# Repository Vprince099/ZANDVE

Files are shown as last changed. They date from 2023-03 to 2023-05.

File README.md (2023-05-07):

# UPDATE 04/04/2023
## Revision Log
* 5/6 Added upgraded Stepper Mounts, Bug fixes on Rear Gantry Panel Base Parts
* 4/4 Type-V stls and cad loaded
* 4/2 Added Built in supports for 6 parts, CAD Complete for Type-V
* 4/1 Parts fixes and cad update 
* 3/31 Added Top Hat XL for users looking to run umbilicals on a canbus
* 3/29 [BOM](https://docs.google.com/spreadsheets/d/1_rfxcacC1YKR7S-sEJu0cIL2j3crcf0YIQrBYNYs7lM/edit?usp=sharing) is complete, I will continue to add links for vendors as time permits. 

## Please see below for the project status.
Work ID | Description | Status | LOE | Target Date |
| :--- | :--- | :--- | :---: | :---: |
1 | Finish upload of Type-Z | Done | Medium | 3/27/23
2.1 | Finish Bom | Done | Medium | 3/29/23
2.2 | Work on a basic Assembly guide | Not Started | High | On-Going
3 | Start Type-V Cad | Done | Low | 4/02/23
3.1 | Build Type-V | Waiting on Parts | Low | 4/30/23
3.2 | Upload Everything for Type-V | Done | Medium | 4/4/22
4 | Implement Hydra for Type-Z | Done | Low | 5/1/23
4.1 | Testing of Hydra | Done | Low | 5/1/23
4.2 | Release V1 of Type Z | Updating CAD | Medium | 5/13/23
5 | Implement Trident for Type-V | Dependant on Type-V Release | High | TBD
5.1 | Testing of Trident | Parts Not Ordered | High | TBD
5.2 | Release V1 of Type-V | Dependant on Testing | Medium | TBD

## Purpose
This is a placeholder for uploading the projects I am working on

<a href="https://www.buymeacoffee.com/VengefulDesign" target="_blank">Buy Me A Coffee</a>

Project ZANDVE is licensed under the
GNU General Public License v3.0<br><br>

Credits to [ZeroGDesign/Mercury](https://github.com/ZeroGDesign/Mercury/)

Credits to [VoronDesign](https://github.com/VoronDesign/)

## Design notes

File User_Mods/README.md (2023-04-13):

# Mods

Printer mods for ZANDVE 3D printers
Remember to update this README when uploading new mod!

[How To Contribute](https://github.com/Vprince099/ZANDVE/blob/61768b7b6e2966e44ad4c9d49aaf2dfaacc2f230/User_Mods/how_to_contribute.md)

***Credit: This idea originates from [ZeroG](https://github.com/Vprince099/UserMods/tree/main/Mercury_One)***

## Directory structure

Create a folder containing your name (without spaces) and create a folder for your mod(s).

Suggested directory layout for your mod:
- `creator_name/`
  - `mod_name/`
    - `README.md` with a description, optionally build instructions and required parts
    - `stl/` folder with stereolithographical models, oriented correctly for printing
    - `cad/` folder with original design files (STEP, F3D, Scad, etc.) (optional)
    - `doc/` folder with supported documentation (optional)
    - `images/` folder with screen shots/renders/etc.

## Table structure

Update the following table with the information about your mod:
- Your name
- A link to your sub-folder
- A short description of your mod
- The build difficulty:
  - `:green_heart:` for :green_heart: (Easy)
  - `:blue_heart:` for :blue_heart: (Intermediate)
  - `:heart:` for :heart: (Advanced)

like so:
`
| Creator | [Mod title](link) | Description | Difficulty `

---

| Creator | Mod title | Description | Difficulty
| --- | --- | --- | --- |
| *JellyBob* | [*ZANDVE_Less-Frame*](./JellyBob/ZANDVE_Less-Frame) | A modification to remove the original front cross extrusion which makes it awkward to see the nozzle on build plate for first layer (poor-man’s 3DO nozzle cam) :)  |:green_heart:
| *LTSpenny* | [*ZANDVE_Left_Stepper Pillow_Bearing*](./LTSPENNY/ZANDVE/L_Stepper_Pillow_Bearing) | A modification to add a pillow bearing reusing readily available parts you should already have plenty of and implementation of Mercury 1.1 Bearing Stack.  |:green_heart:

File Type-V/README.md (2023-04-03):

# ZANDVE Enclosed E5+ Printer Code Name: Type V (**Files Loading Soon**)

This mod is is amalgamation of parts from the ZeroG (Mercury1) and Voron (Trident,V1.8,StealthBurner) for the Ender 5 Plus. The primary goal is to provide a enclosed Core-xy printer in similar fashion to Voron design language while still retaining the majority of the E5+ Frame and Z-Motion Systems.   

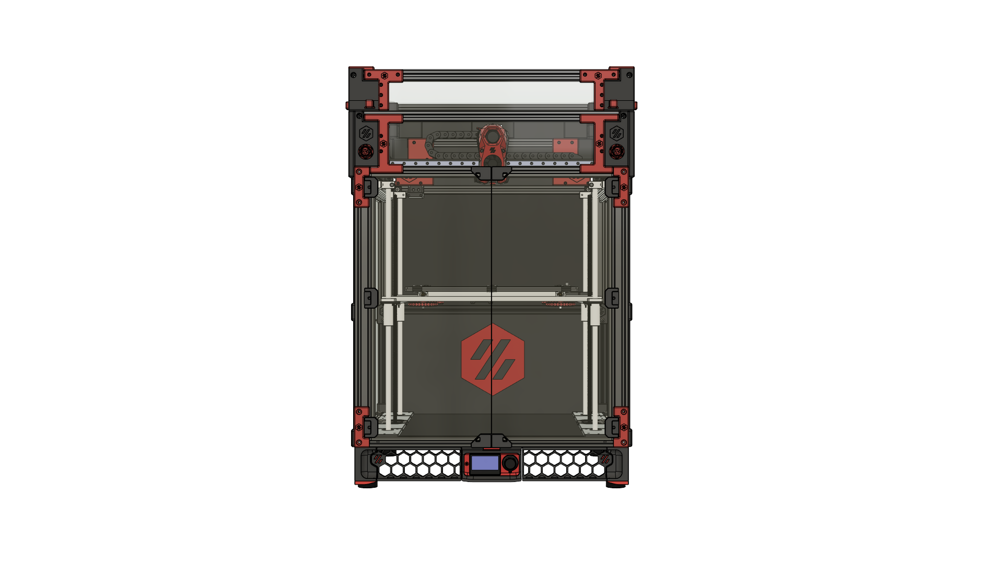
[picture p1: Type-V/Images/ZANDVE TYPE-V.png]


## Description

This version is targeted at anyone looking to retain the **VORON** badging. The **ZERO G** badged version can be found here [Type-Z](https://github.com/Vprince099/ZANDVE/tree/main/Type-Z). In order to provide a version that can be used by the entire E5 Plus community, I am starting with stock Z-Motion (a new upgrade will be released soon to allow for the tri-stepper upgrade Trident by Voron). 

This Version is intended to reduce the cost of conversion while still providing a Fully Enclosed CORE-XY Printer: 

* Estimated Conversion Cost from Stock **TBD**
* Estimated Conversion Cost from Mercury 1/1.1 **TBD**

## Dependencies

* **Please print in ABS or ASA**
* Due to the tight clearances of a part like this, I recommend this part be printed on a properly calibrated printer
* I **Do not** recommend scaling the parts via a slicer as you may have issues with fitment

## Bill of Materials

[BOM](https://docs.google.com/spreadsheets/d/1_rfxcacC1YKR7S-sEJu0cIL2j3crcf0YIQrBYNYs7lM/edit?usp=sharing), vendors and other sources will be added as time permits.

## Help

* Please reach out to me directly on discord if you have any issues or suggestions for this Mod 

## Authors

Vprince099 aka Vengeful Discord - Vengeful#8648

## Version History
    
* 0.1
    * Initial Release

## License

This project is licensed under the GNU GENERAL PUBLIC LICENSE - see the LICENSE.md file for details

## Acknowledgments

* ZeroG - Original Towers used to expand upon [Link to Project](https://github.com/ZeroGDesign/Mercury.git)
* Voron Design - V0 Team for Knob and Thread Appendage [Link to Project](https://github.com/VoronDesign/Voron-0.git)

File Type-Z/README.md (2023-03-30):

# ZANDVE Enclosed E5+ Code Name: Type Z

This mod is an amalgamation  of parts from the ZeroG (Mercury1) and Voron (Trident,V1.8,V0,StealthBurner) for the Ender 5 **PLUS**. The primary goal is to provide a enclosed Core-xy printer in similar fashion to Voron design language while still retaining the majority of the E5+ Frame and Z-Motion Systems.   

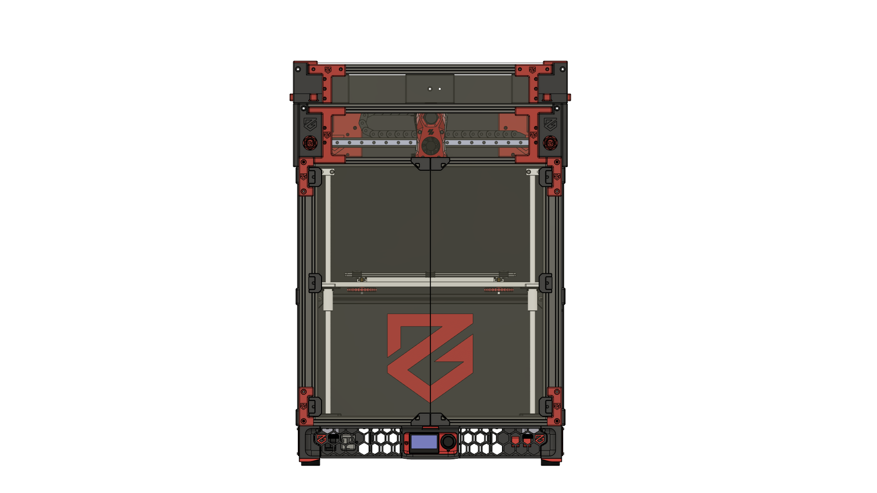
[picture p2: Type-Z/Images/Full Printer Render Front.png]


## Description

This version is targeted at anyone looking to retain the **ZERO G** badging. The **VORON** badged version can be found here [Type-V](https://github.com/Vprince099/ZANDVE/tree/main/Type-V). In order to provide a version that can be used by the entire E5 Plus community, I am starting with stock Z-Motion (a new upgrade will be released soon to allow for the tri-stepper upgrade HYDRA by ZERO G). 

This Version is intended to reduce the cost of conversion while still providing a Fully Enclosed CORE-XY Printer: 

* Estimated Conversion Cost from Stock **TBD**
* Estimated Conversion Cost from Mercury 1/1.1 **TBD**

## Dependencies

* **Please print in ABS or ASA**
* Due to the tight clearances of a part like this, I recommend this part be printed on a properly calibrated printer
* I **Do not** recommend scaling the parts via a slicer as you may have issues with fitment

## Bill of Materials

[BOM](https://docs.google.com/spreadsheets/d/1_rfxcacC1YKR7S-sEJu0cIL2j3crcf0YIQrBYNYs7lM/edit?usp=sharing), vendors and other sources will be added as time permits.

## Help

* Please reach out to me directly on discord if you have any issues or suggestions for this Mod 

## Authors

Vprince099 aka Vengeful Discord - Vengeful#8648

## Version History
    
* 0.1
    * Initial Release

## License

This project is licensed under the GNU GENERAL PUBLIC LICENSE - see the LICENSE.md file for details

## Acknowledgments

* Credits to [ZeroGDesign/Mercury](https://github.com/ZeroGDesign/Mercury/)
* Credits to [VoronDesign](https://github.com/VoronDesign/)

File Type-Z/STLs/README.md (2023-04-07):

* Can Bus adapter for Cable chains [link](https://www.printables.com/model/320325-btt-ebb36-canbus-voron-cw2-mount-moons-pancake-mot)
* Stealthburner Parts [link](https://github.com/VoronDesign/Voron-Stealthburner.git)

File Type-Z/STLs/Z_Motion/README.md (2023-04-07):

# Credits 
* Z Stepper Mounts from [VoronDesign](https://github.com/VoronDesign/)

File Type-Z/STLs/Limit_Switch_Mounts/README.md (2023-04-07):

# Credits 
* Beacon SB Xcarriage from [Annex](https://github.com/Annex-Engineering/Annex-Engineering_User_Mods/tree/main/Printers/Non_Annex_Printers/VORON_Printers/VORON_V2dot4/annex_dev-stealthburner_beacon_x_c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)
* Mech endstop retrofitted from Voron Trident [VoronDesign](https://github.com/VoronDesign/)
* X-endstop [ZeroGDesign/Mercury](https://github.com/ZeroGDesign/Mercury/) styling
* Badging added to match [ZeroGDesign/Mercury](https://github.com/ZeroGDesign/Mercury/) styling
* All other parts are unique to the ZANDVE

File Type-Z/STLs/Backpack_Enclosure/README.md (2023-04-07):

# Credits 
* Parts retrofitted from Voron 1.8 [VoronDesign](https://github.com/VoronDesign/)
* Adapted to mount on 2040 Extrusions

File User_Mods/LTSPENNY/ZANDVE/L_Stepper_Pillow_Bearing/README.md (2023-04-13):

**Purpose:** Using the standard NEMA17 stepper motor 17HE19-2004S from Mercury 1.1 BOM with ZANDVE Build, found that the Left Stepper Mount toothed gear was on the far edge of the stepper shaft. This can cause issues with the shaft receiving side loads and leading to bending the shaft, breaking or early failure of stepper. After discussing with jellybob and Vprince099, the solution to be implemented is a new stepper mount configuration being added to the ZANDVE BOM. New steppers will have longer shafts with a bearing on the bottom stepper mount. Interim, I modded the files to add a pillow block with items you should have readily available from the Ender 5/plus teardown. I've also modified the slots for the bearing stacks to accomodate the extra shims in the new Merc. 1.1 release that aliviates possible belt wear issues experienced with previous versions.

Printing Instructions:
* All ZANDVE STL Slicer settings Apply. ASA/ABS
* Print with supports on build plate. 
* Locate old V-Slot wheel, use a 5mm shaft or similar to push or pull one of the bearings out.
* Press fit bearing on the side the Toothed Gear will go into.
* Assemble steppers onto top stepper mount, install toothed gear. 
* Assemble rest as normal.

* **Version Changes**
* **V.0** - Original Pillow Block addition to Left Stepper Mount
* **V.1** - Added space to allow full Mercury 1.1 Bearing Stack install. (**CURRENT UPLOADED VERSION**)

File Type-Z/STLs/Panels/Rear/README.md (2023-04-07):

# Credits 
* Parts retrofitted from Voron Trident [VoronDesign](https://github.com/VoronDesign/)
* Same clips as Trident 4mm
* Added 2020 Etrusion endcaps due to 2040 Rear Frame

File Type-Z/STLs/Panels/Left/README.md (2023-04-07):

# Credits 
* Parts retrofitted from Voron Trident [VoronDesign](https://github.com/VoronDesign/)
* Same clips as Trident 4mm

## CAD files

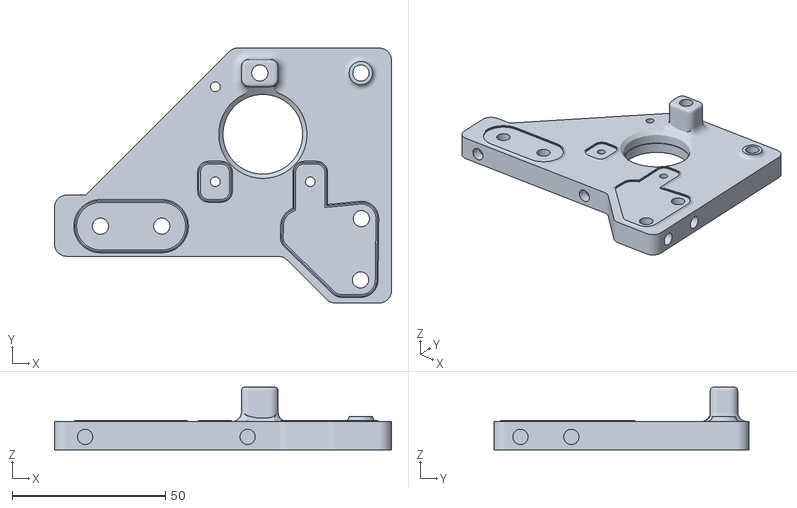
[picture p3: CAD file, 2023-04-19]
Type-Z/STLs/Rear_Steppers/Standard/Left/L Main Top Plate Pocket.stl
110.0 x 83.2 x 20.5

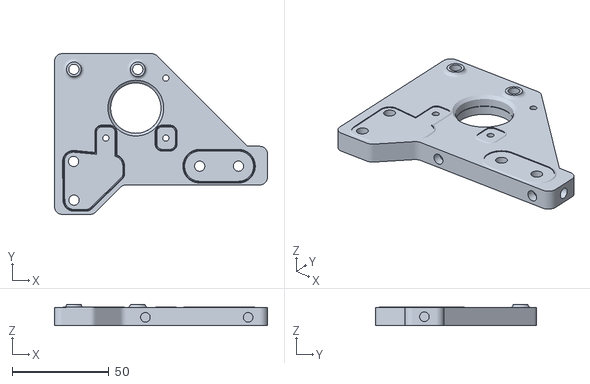
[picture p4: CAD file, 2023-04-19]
Type-Z/STLs/Rear_Steppers/Standard/Right/R Main Top Plate Pocket.stl
110.0 x 83.1 x 10.9

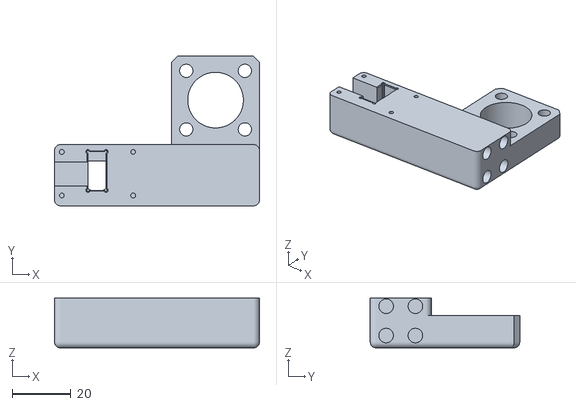
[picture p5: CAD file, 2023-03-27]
Type-Z/STLs/Limit_Switch_Mounts/Mech_Z_Endstop_Assembly.stl
70.0 x 51.1 x 17.0

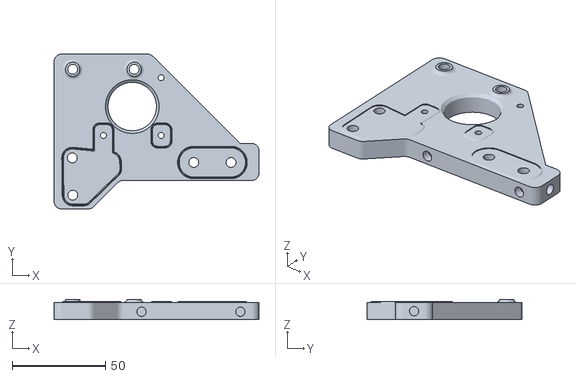
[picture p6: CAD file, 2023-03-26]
Type-Z/STLs/Rear_Steppers/Max Power/Right/R Main Top Plate.stl
110.0 x 83.1 x 10.9

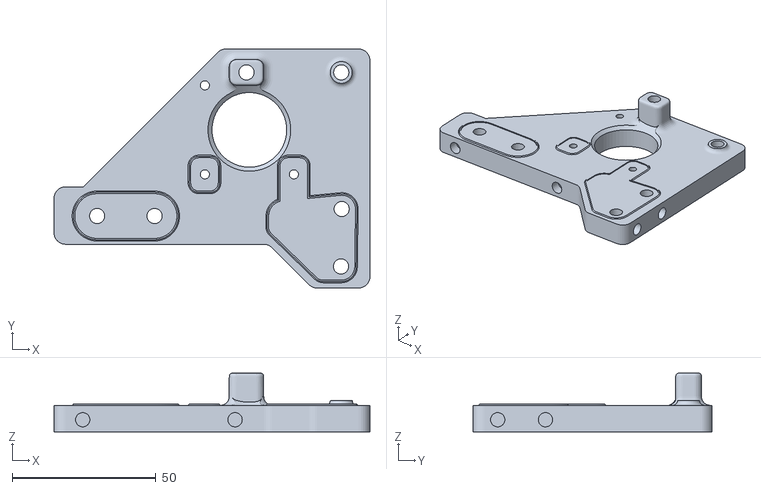
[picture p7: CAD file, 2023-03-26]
Type-Z/STLs/Rear_Steppers/Max Power/Left/L Main Top Plate.stl
110.0 x 83.2 x 20.5

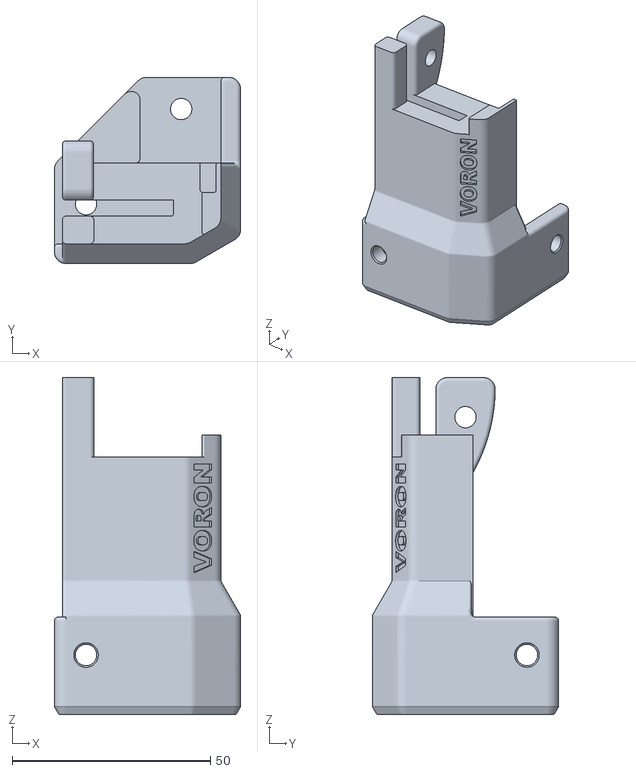
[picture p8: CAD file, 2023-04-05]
Type-V/STLs/Backpack_Enclosure/E5+_Backpack_Corner_Bracket_Right.stl
47.0 x 47.0 x 85.0

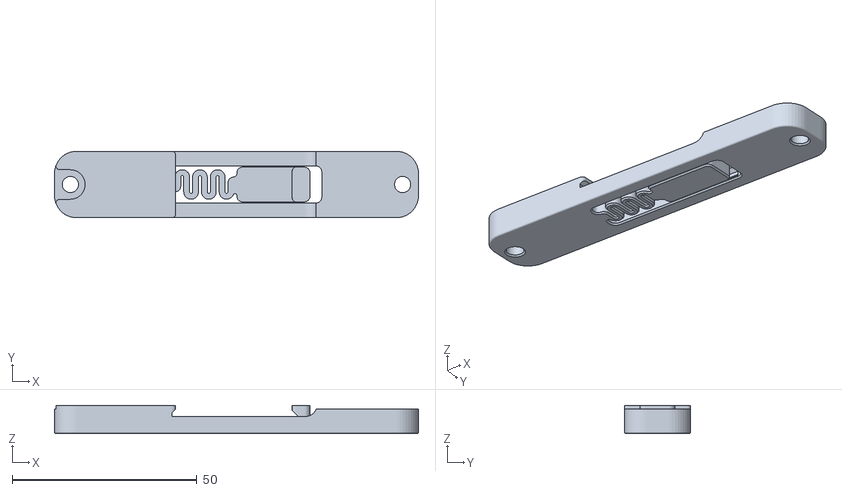
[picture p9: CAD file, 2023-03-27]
Type-V/STLs/Electronics/RSP-500-24 Din Bracket x2.stl
98.6 x 18.0 x 7.60

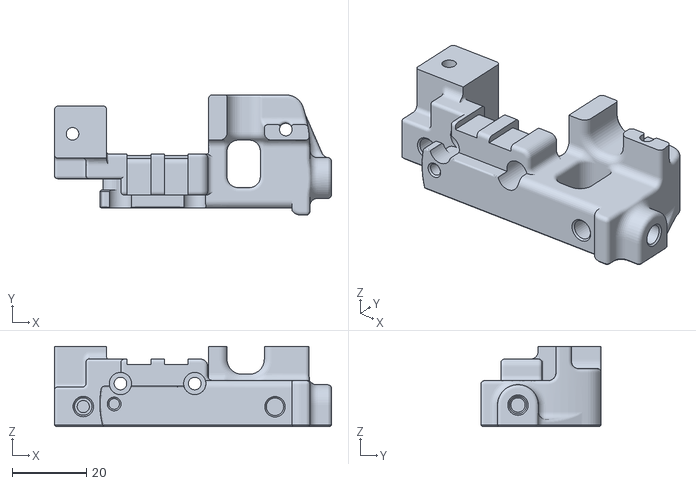
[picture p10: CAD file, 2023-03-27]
Type-V/STLs/Limit_Switch_Mounts/Beacon_SB_Xcarriage-Left.stl
74.6 x 32.4 x 21.6

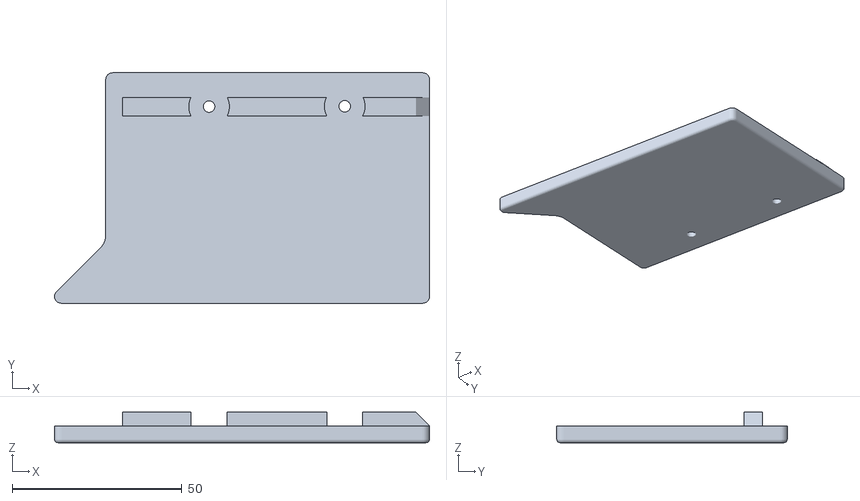
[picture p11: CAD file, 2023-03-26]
Type-V/STLs/Panels/Deck/Front Mid Cover_Left.stl
110.6 x 68.0 x 9.00

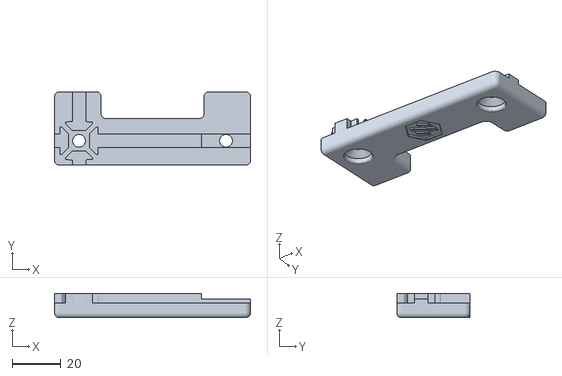
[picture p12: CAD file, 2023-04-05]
Type-V/STLs/Panels/Front/Hinge_Cover_Bot_Left[acc].stl
80.0 x 30.0 x 10.0

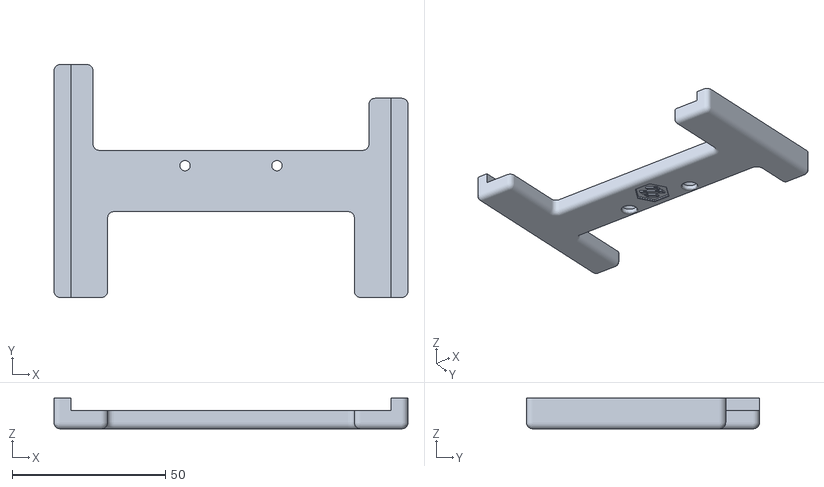
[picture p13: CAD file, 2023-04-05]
Type-V/STLs/Panels/Gantry/Front/Front Panel Lid - Left[acc].stl
115.5 x 76.0 x 10.0

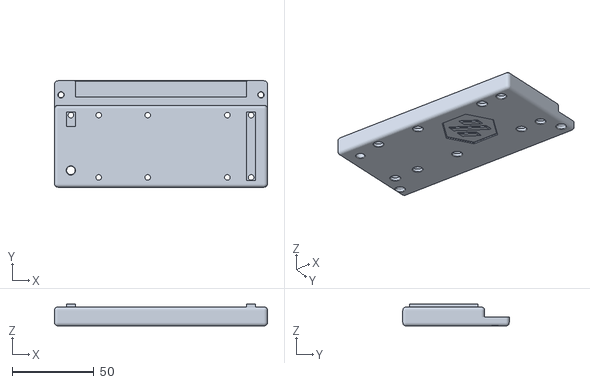
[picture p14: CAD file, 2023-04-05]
Type-V/STLs/Panels/Gantry/Left/L_Plate_11mm_Logo.stl
130.0 x 65.0 x 13.2

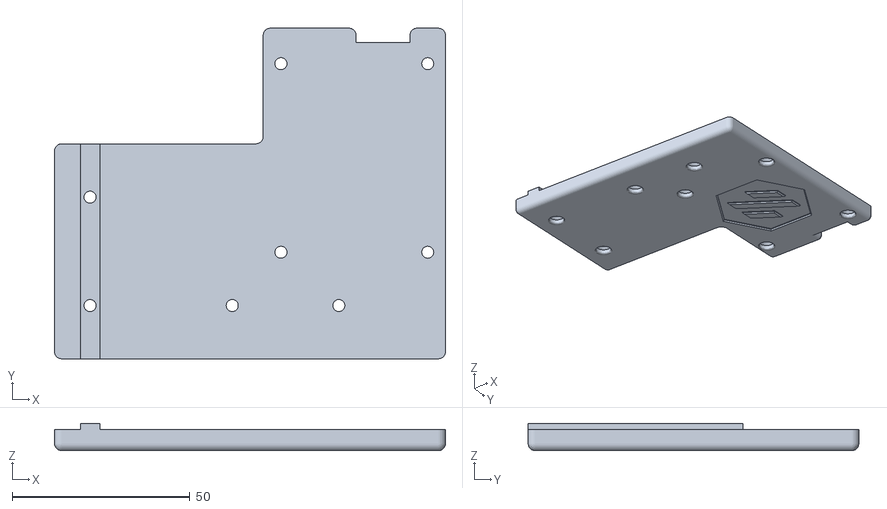
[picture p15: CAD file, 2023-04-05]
Type-V/STLs/Panels/Gantry/Rear/Rear Panel Lid - Left[acc].stl
110.0 x 93.0 x 7.70

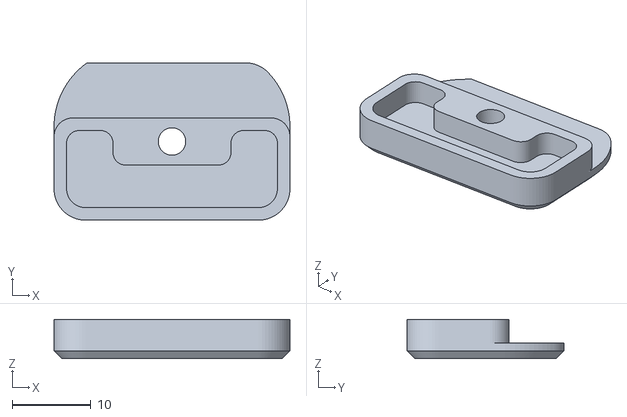
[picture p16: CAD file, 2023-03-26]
Type-V/STLs/Panels/Left/Midspan Panel Retainer 3mm x4.stl
30.0 x 20.0 x 5.00

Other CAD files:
Type-V/CAD/ZANDVE_TYPE-V_0_1.step
Type-V/STLs/Panels/Gantry/Right/R_Plate_11mm_Logo.stl
Type-V/STLs/Panels/Rear/Corner Panel Retainer 3mm x2.stl
Type-V/STLs/Panels/Right/Corner Panel Retainer 3mm x4.stl
Type-V/STLs/Backpack_Enclosure/E5+_Backpack_Corner_Bracket_Left.stl
Type-V/STLs/Backpack_Enclosure/[a]_latch_left.stl
Type-V/STLs/Backpack_Enclosure/[a]_latch_right.stl
Type-V/STLs/Backpack_Enclosure/[a]_lever_left.stl
Type-V/STLs/Backpack_Enclosure/[a]_lever_right.stl
Type-V/STLs/Backpack_Enclosure/backpack_base_left.stl
Type-V/STLs/Backpack_Enclosure/backpack_base_right.stl
Type-V/STLs/Backpack_Enclosure/controller_fan_mount.stl
Type-V/STLs/Backpack_Enclosure/din_base_x4.stl
Type-V/STLs/Backpack_Enclosure/din_clamp_x4.stl
Type-V/STLs/Backpack_Enclosure/lock_body_x2.stl
Type-V/STLs/Backpack_Enclosure/panel_holder_x2.stl
Type-V/STLs/Electronics/DIN_center_support_x4.stl
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

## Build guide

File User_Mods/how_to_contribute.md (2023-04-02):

# How to contribute

Credit: https://github.com/dweight

In order to contribute your mod you need to follow these steps:

1. Make sure you are logged into github (or create an account)
2. Go to [UserMods Repo](https://github.com/Vprince099/ZANDVE/tree/main/User_Mods)
3. Fork the repository

4. Upload your files to the right directory (make sure you are in the right repository)
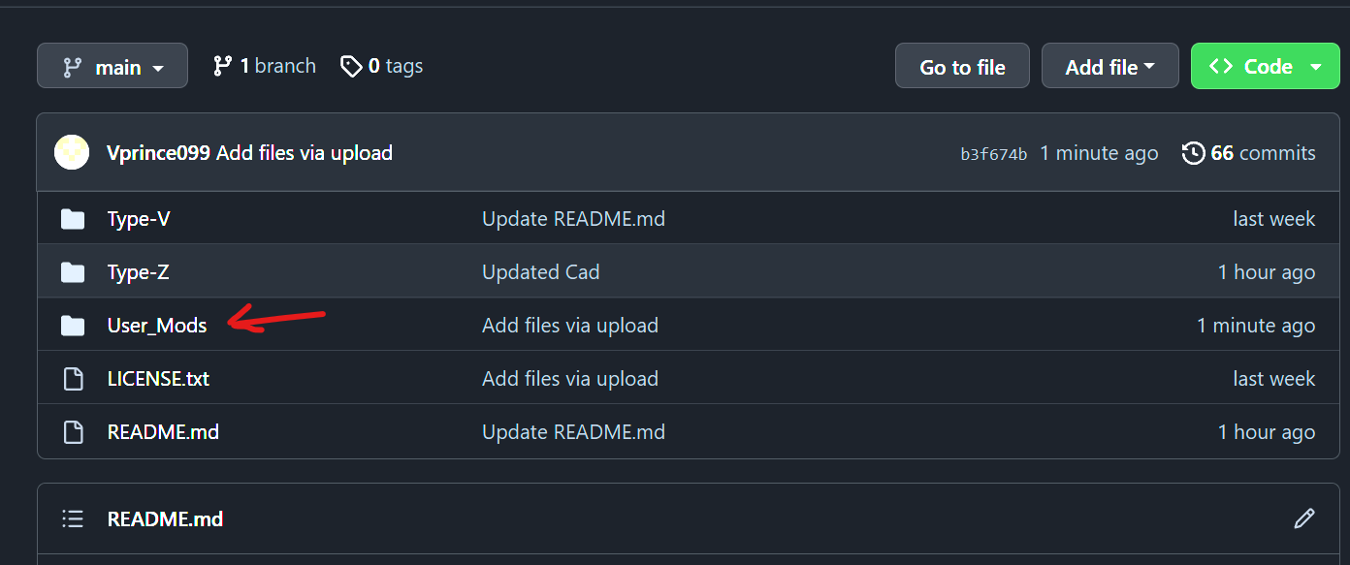
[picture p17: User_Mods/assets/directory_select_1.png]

5. Add your files
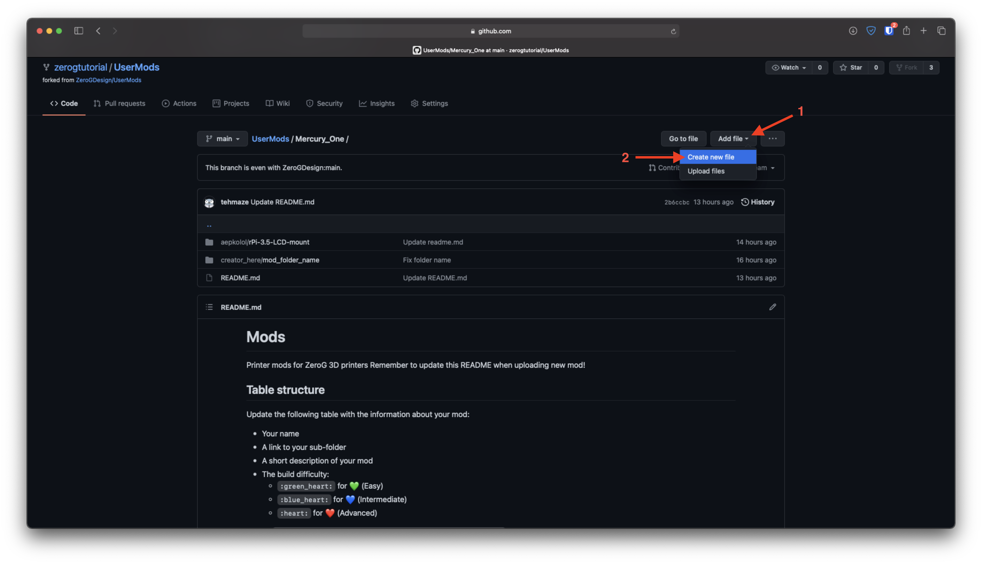
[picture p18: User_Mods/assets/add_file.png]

	1. Click on `Add files`
	2. Click `Create new file`
6. Create a directory structure containing your nickname followed by `/` and mod name
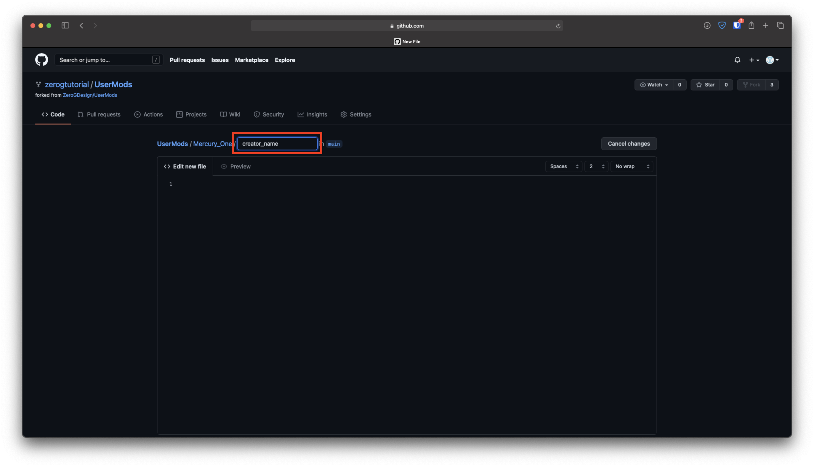
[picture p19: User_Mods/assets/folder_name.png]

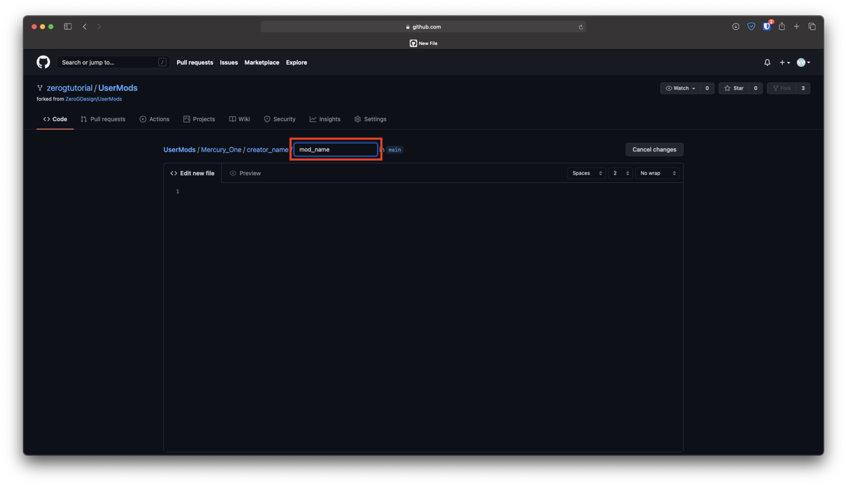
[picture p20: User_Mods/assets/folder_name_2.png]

7. Drag and drop the file you want to upload (2), remember also to name it (1)
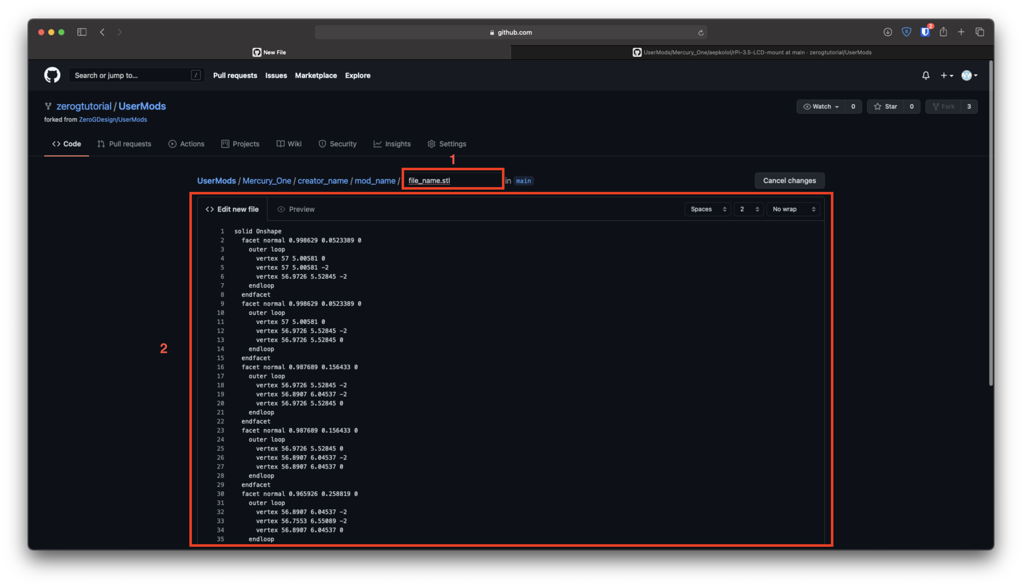
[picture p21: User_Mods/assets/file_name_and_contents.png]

8. Commit the file
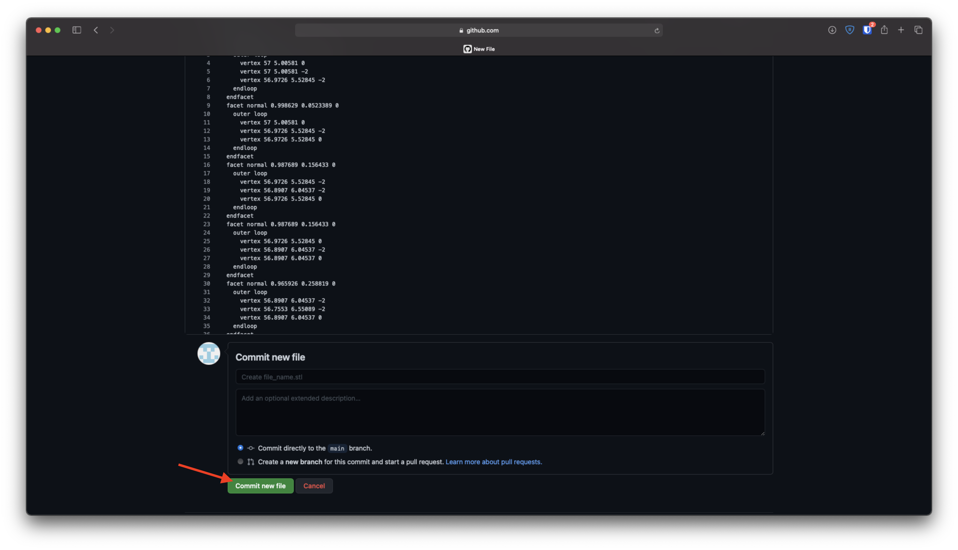
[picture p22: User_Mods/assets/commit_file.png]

9. Edit `README.md` by adding your mod to the table (remember to commit the edited file!)
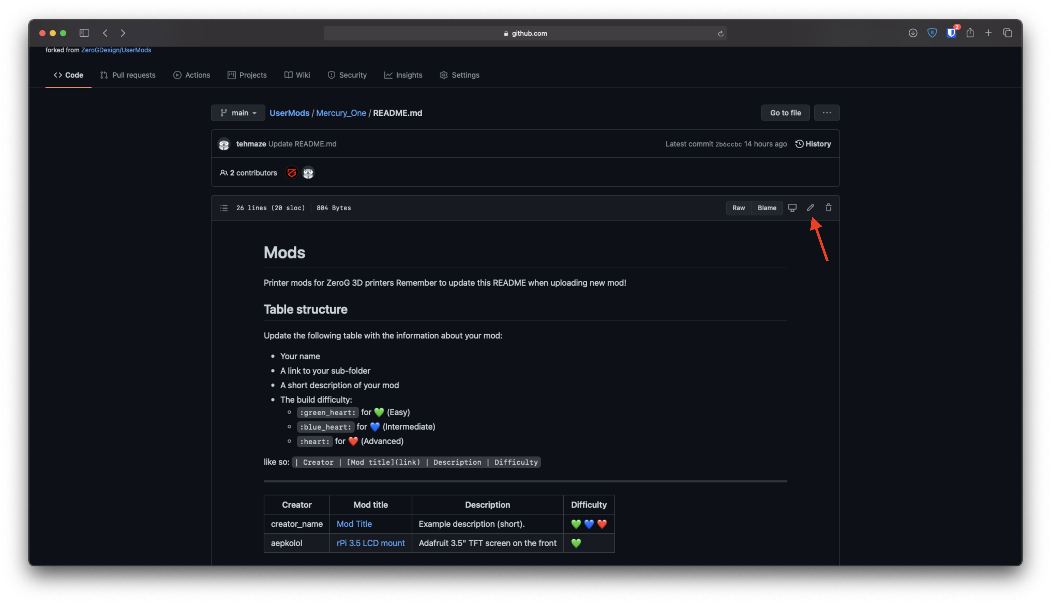
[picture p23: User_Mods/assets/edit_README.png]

10. Go to Pull reqests section
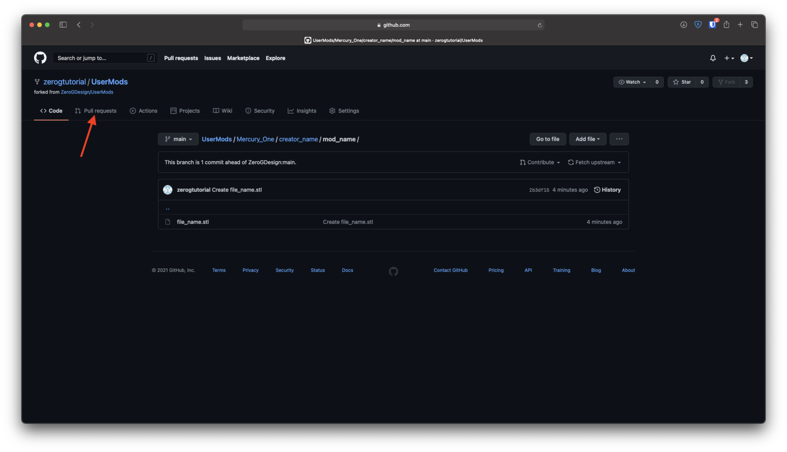
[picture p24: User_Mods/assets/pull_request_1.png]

11. Click on `New pull request` button
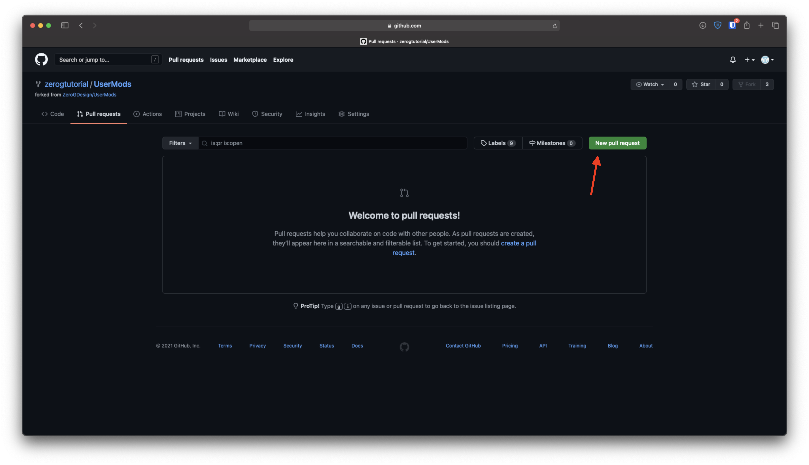
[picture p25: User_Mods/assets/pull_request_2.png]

12. Make sure you are targetting a correct branch (1) and click on `Create pull request` (2)
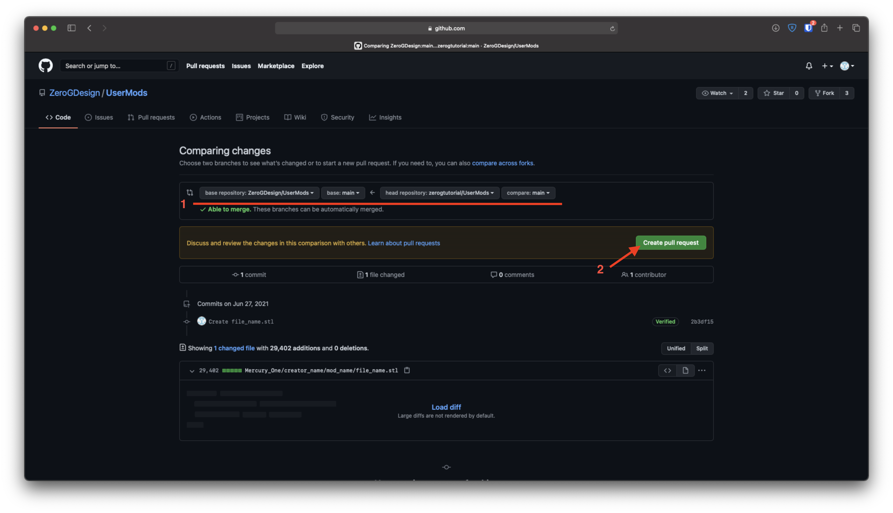
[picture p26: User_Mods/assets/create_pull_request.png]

13. Wait for your request being approved and merged into UserMods repo

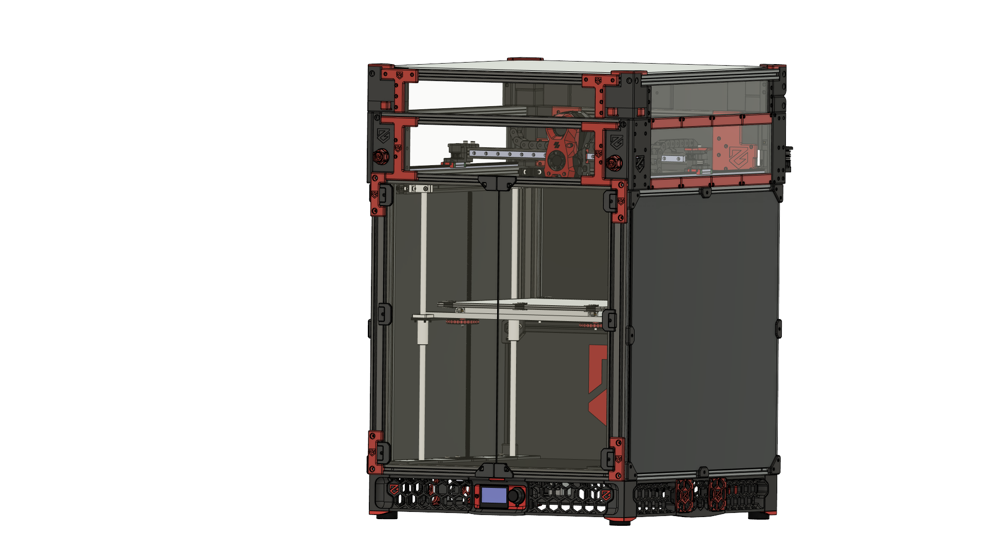
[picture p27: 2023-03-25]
Type-Z/Images/Full Printer Render.png

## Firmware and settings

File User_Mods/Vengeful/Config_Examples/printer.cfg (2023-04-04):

[include fluidd.cfg]
# [include klicky-probe.cfg]
[include stealthburner_leds.cfg]
# [include autoz.cfg]
[output_pin motor_power]
pin: PC13
value: 1
[exclude_object] 

[mcu]
serial: /dev/serial/by-id/usb-Klipper_stm32f429xx_200049000250315637383220-if00

[mcu EBBCan]
# serial: /dev/serial/by-id/usb-Klipper_Klipper_firmware_12345-if00
canbus_uuid: fad101eb7092

[adxl345]
cs_pin: EBBCan: PB12
spi_software_sclk_pin: EBBCan: PB10
spi_software_mosi_pin: EBBCan: PB11
spi_software_miso_pin: EBBCan: PB2
axes_map: x,y,z

[printer]
kinematics: corexy
max_velocity: 300  
max_accel: 3000
max_z_velocity: 15
max_z_accel: 50
square_corner_velocity: 5.0 

[thermistor NTC_100K]
temperature1: 25
resistance1: 100000
beta: 3950

########################################
# Temp
########################################
# [temperature_sensor PI3-LePotato]
# sensor_type: temperature_host

# [temperature_sensor SKR2-MCU]
# sensor_type: temperature_mcu

[temperature_sensor Chamber_Temp]
sensor_type: Generic 3950
sensor_pin: PA3 # PB1 is EOSTOP on the Sensor headers. Has a 3 pin. Use left 2 pins. Connect other leg of thermistor to ground
# pullup_resistor: 10000

[temperature_sensor CANBOARD]
sensor_type: temperature_mcu
sensor_mcu: EBBCan

#####################################################################
#   X/Y Stepper Settings
#####################################################################

[stepper_x]
step_pin: PE2
dir_pin: PE1
enable_pin: !PE3
microsteps: 16
rotation_distance: 40
endstop_pin: PC1
position_min: 0
position_max: 370
position_endstop: 370
homing_speed: 40
homing_retract_dist: 5

[tmc2209 stepper_x]
uart_pin: PE0
# diag_pin: ^PC1
interpolate: False
run_current: 0.9
# hold_current: 0.7
sense_resistor: 0.110
stealthchop_threshold: 0
# driver_SGTHRS: 90 # this is set to 255 which is the MAX sensitivity for sensorless homing, you will need to tune this later

[stepper_y]
step_pin: PD5
dir_pin: PD4
enable_pin: !PD6
microsteps: 16
rotation_distance: 40
endstop_pin: PC3  
position_min: 0
position_max: 355
position_endstop: 355
homing_speed: 50
homing_retract_dist: 5

[tmc2209 stepper_y]
uart_pin: PD3
# diag_pin: ^PC3
interpolate: False
run_current: 0.9
# hold_current: 0.7
sense_resistor: 0.110
stealthchop_threshold: 0
# driver_SGTHRS: 90 # this is set to 255 which is the MAX sensitivity for sensorless homing, you will need to tune this later

#####################################################################
#   Z Stepper Settings
#####################################################################

## Z0 Stepper - Left Z Motor
## Z Stepper Socket
[stepper_z]
step_pin: PA15
dir_pin: !PA8
enable_pin: !PD1
microsteps: 16

# Rotation Distance for TR8x8 = 8, TR8x4 = 4, TR8x2 = 2
rotation_distance: 8            
full_steps_per_rotation: 200    #200 for 1.8 degree, 400 for 0.9 degree

# endstop_pin: PA0
endstop_pin: probe:z_virtual_endstop
##  Z-position of nozzle (in mm) to z-endstop trigger point relative to print surface (Z0)
##  (+) value = endstop above Z0, (-) value = endstop below
##  Increasing position_endstop brings nozzle closer to the bed
##  After you run Z_ENDSTOP_CALIBRATE, position_endstop will be stored at the very end of your config
# position_endstop: -0.2
position_max: 400
position_min: -5
homing_speed: 8.0 # Leadscrews are slower than 2.4, 10 is a recommended max.
second_homing_speed: 3.0
homing_retract_dist: 0

[tmc2208 stepper_z]
uart_pin: PD0
interpolate: False
run_current: 0.900
# hold_current: 0.5
sense_resistor: 0.110
# stealthchop_threshold: 0

##  Z1 Stepper - Right Z Motor
##  E0 Stepper Socket
[stepper_z1]
step_pin: PD11
dir_pin: !PD10
enable_pin: !PD13
## Remember to mirror these changes in stepper_z! (there are two motors)
rotation_distance: 8            
microsteps: 16
full_steps_per_rotation: 200    #200 for 1.8 degree, 400 for 0.9 degree


[tmc2208 stepper_z1]
uart_pin: PD12
interpolate: False
run_current: 0.900
# hold_current: 0.5
sense_resistor: 0.110
# stealthchop_threshold: 0

#####################################################################
#   Probe
#####################################################################

# [probe]

#  If your probe is NO instead of NC, add change pin to !P0.10
# pin: EBBCan: PB6
# x_offset: 0
# y_offset: 19.75
#z_offset: 6.42
# speed: 2.5
# samples: 3
# samples_result: median
# sample_retract_dist: 2.0
# samples_tolerance: 0.01
# samples_tolerance_retries: 5

[beacon]
serial: /dev/serial/by-id/usb-Beacon_Beacon_RevD_C7D29646515137474C202020FF0D0B18-if00
#   Path to the serial port for the beacon device. Typically has the form
#   /dev/serial/by-id/usb-Beacon_Beacon_...
# speed: 5
#   Z probing dive speed.
# lift_speed: 5
#   Z probing lift speed.
backlash_comp: 0.02516
#   Backlash compensation distance for removing Z backlash before measuring
#   the sensor response.
x_offset: 0.
#   X offset of beacon from the nozzle.
y_offset: 18.8
#   Y offset of beacon from the nozzle.
#trigger_distance: 2.
#   Beacon trigger distance for homing.
#trigger_dive_threshold: 1.
#   Threshold for range vs dive mode probing. Beyond `trigger_distance +
#   trigger_dive_threshold` a dive will be used.
#trigger_hysteresis: 0.006
#   Hysteresis on trigger threshold for untriggering, as a percentage of the
#   trigger threshold.
#cal_nozzle_z: 0.1
#   Expected nozzle offset after completing manual Z offset calibration.
#cal_floor: 0.2
#   Minimum z bound on sensor response measurement.
#cal_ceil: 5.
#   Maximum z bound on sensor response measurement.
#cal_speed: 1.
#   Speed while measuring response curve.
#cal_move_speed: 10.
#   Speed while moving to position for response curve measurement.
#default_model_name: default
#   Name of default beacon model to load.
mesh_main_direction: x
#   Primary travel direction during mesh measurement.
#mesh_overscan: -1
#   Distance to use for direction changes at mesh line ends. Omit this setting
#   and a default will be calculated from line spacing and available travel.
#mesh_cluster_size: 1
#   Radius of mesh grid point clusters.
mesh_runs: 2
#   Number of passes to make during mesh scan.
#####################################################################
#   Extruder
#####################################################################

#   Driver Socket E1

[extruder]
step_pin: EBBCan: PD0
dir_pin: EBBCan: PD1
enable_pin: !EBBCan: PD2
# microsteps: 16
rotation_distance: 21.18   #Bondtech 5mm Bore Drive Gears
gear_ratio: 50:10               #BMG Gear Ratio
microsteps: 16
full_steps_per_rotation: 200    #200 for 1.8 degree, 400 for 0.9 degree
nozzle_diameter: 0.400
filament_diameter: 1.750
pressure_advance: 0.04
heater_pin: EBBCan: PB13
sensor_type: ATC Semitec 104NT-4-R025H42G
sensor_pin: EBBCan: PA3
#control: pid
#pid_Kp: 22.2
#pid_Ki: 1.08
#pid_Kd: 114
min_temp: 0
max_temp: 350
#  If using pt100 or pt1000
# sensor_type:MAX31865
# sensor_pin: EBBCan: PA4
# spi_bus: spi1
# rtd_nominal_r: 100
# rtd_reference_r: 430
# rtd_num_of_wires: 2

[tmc2209 extruder]
uart_pin: EBBCan: PA15
interpolate: False
run_current: 0.5
# hold_current: 0.4
# sense_resistor: 0.110
stealthchop_threshold: 0


#####################################################################
#   Bed Heater
#####################################################################
[heater_bed]
heater_pin: PD7
sensor_type: Generic 3950
sensor_pin: PA1
#control: pid
#pid_Kp: 22.2
#pid_Ki: 1.08
#pid_Kd: 114
min_temp: 0
max_temp: 130

#####################################################################
#   Fan Control
#####################################################################

[heater_fan hotend_fan]
##  Hotend Fan - HE1 Connector
pin: EBBCan: PA0
max_power: 1.0
kick_start_time: 0.5
heater: extruder
heater_temp: 50.0
##  If you are experiencing back flow, you can reduce fan_speed
#fan_speed: 1.0

[fan]
##  Print Cooling Fan - Fan Pin
pin: EBBCan: PA1
kick_start_time: 0.5
##  Depending on your fan, you may need to increase this value
##  if your fan will not start. Can change cycle_time (increase)
##  if your fan is not able to slow down effectively
off_below: 0.10

[temperature_fan MCU_Enclosure]
pin: PB5
# max_power: 1
# kick_start_time: 0.5
# fan_speed: 0.50
sensor_type: temperature_mcu
# sensor_mcu: skr
min_temp: 23
max_temp: 60
target_temp: 50
control: watermark

[temperature_fan PSU_Enclosure]
pin: PB6
# max_power: 1
# kick_start_time: 0.5
# fan_speed: 0.50
sensor_type: temperature_host
min_temp: 23
max_temp: 60
target_temp: 50
control: watermark
# Due to BTT implementing a Marlin-specific safety feature,
# "anti-reversal stepper protection", this pin needs pulling
# high to pass power to stepper drivers and most FETs




#####################################################################
#   LED Control
#####################################################################
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

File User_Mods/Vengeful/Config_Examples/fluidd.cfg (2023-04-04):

[virtual_sdcard]
path: /home/pi/printer_data/gcodes

[pause_resume]

[display_status]

[gcode_macro CANCEL_PRINT]
description: Cancel the actual running print
rename_existing: CANCEL_PRINT_BASE
gcode:
    TURN_OFF_HEATERS
    CANCEL_PRINT_BASE

[gcode_macro PAUSE]
description: Pause the actual running print
rename_existing: PAUSE_BASE
# change this if you need more or less extrusion
variable_extrude: 1.0
gcode:
    ##### read E from pause macro #####
    {% set E = printer["gcode_macro PAUSE"].extrude|float %}
    ##### set park positon for x and y #####
    # default is your max posion from your printer.cfg
    {% set x_park = printer.toolhead.axis_maximum.x|float - 5.0 %}
    {% set y_park = printer.toolhead.axis_maximum.y|float - 5.0 %}
    ##### calculate save lift position #####
    {% set max_z = printer.toolhead.axis_maximum.z|float %}
    {% set act_z = printer.toolhead.position.z|float %}
    {% if act_z < (max_z - 2.0) %}
        {% set z_safe = 2.0 %}
    {% else %}
        {% set z_safe = max_z - act_z %}
    {% endif %}
    ##### end of definitions #####
    PAUSE_BASE
    G91
    {% if printer.extruder.can_extrude|lower == 'true' %}
      G1 E-{E} F2100
    {% else %}
      {action_respond_info("Extruder not hot enough")}
    {% endif %}
    {% if "xyz" in printer.toolhead.homed_axes %}
      G1 Z{z_safe} F900
      G90
      G1 X{x_park} Y{y_park} F6000
    {% else %}
      {action_respond_info("Printer not homed")}
    {% endif %} 
    
[gcode_macro RESUME]
description: Resume the actual running print
rename_existing: RESUME_BASE
gcode:
    ##### read E from pause macro #####
    {% set E = printer["gcode_macro PAUSE"].extrude|float %}
    #### get VELOCITY parameter if specified ####
    {% if 'VELOCITY' in params|upper %}
      {% set get_params = ('VELOCITY=' + params.VELOCITY)  %}
    {%else %}
      {% set get_params = "" %}
    {% endif %}
    ##### end of definitions #####
    {% if printer.extruder.can_extrude|lower == 'true' %}
      G91
      G1 E{E} F2100
    {% else %}
      {action_respond_info("Extruder not hot enough")}
    {% endif %}  
    RESUME_BASE {get_params}

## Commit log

2023-03-26 Added Panel Section
    [Corner Panel Retainer 3mm x2.stl, Corner Panel Retainer 3mm x4.stl, Deck Front Left Lid.stl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]
2023-03-26 Added Top Hat and added accent marker to panels
    [FL Corner.stl, FL Front Panel Lid[acc].stl, FL Inner Panel Lid.stl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]
2023-03-26 Adding Rear Steppers
    [L Bottom Plate.stl, L Frame Top Plate.stl, L Main Top Plate.stl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]
2023-03-27 Backpack Enclosure Added
    [E5+_Backpack_Corner_Bracket_Left.stl, E5+_Backpack_Corner_Bracket_Right.stl, [a]_latch_left.stl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]
2023-03-27 Tension Towers Added
    [L_Frame_Enclosure Supports Needed.stl, L_Tensioner[acc].stl, L_Tensioner_Knob[acc].stl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]
2023-03-27 Added Z Motion Mounts
    [Klicky Dock Mount.stl, Mech_Z_Endstop_Assembly.stl, Wago Mount Lid.stl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]
2023-03-27 clean up and added endstop section
    [Beacon_SB_Xcarriage-Left.stl, Beacon_SB_Xcarriage-Right.stl, Cable Chain Bridge_Y Limit.stl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]
2023-03-27 Adding X Mounts
    [L_Bottom_Left.stl, L_Top_Left.stl, R_Bottom_right.stl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]
2023-03-27 Added Skirt Pre Build Parts
    [Corner_A_x2.stl, Corner_B_x2.stl, [a]_btt_knob_light_shield.stl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]
2023-03-27 Added Skirt Post Build Parts
    [Rear_Center_Skirt_E5Plus_Type_Z.stl, Side_Fan_Support_x2.stl, Skirt_E5+_Front_Left.stl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]
2023-03-27 Added Endcaps
    [Type-Z_2020_Endcap_Cover.stl]
2023-03-27 Added Useful Tools
    [Rail alignment tool x 2.stl, ZeroGCube30x30.stl]
2023-03-27 Added Electonics Mounts
    [DIN_center_support_x4.stl, DIN_frame_mount_x4_corrected.stl, E5 Heated Bed Controller v3.stl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]
2023-03-27 adding step
    [ZANDVE_TYPE-Z_0_1.step]
2023-03-30 Update README.md
    Adding BOM Update
2023-03-30 Update README.md
    Added BOM Link
2023-04-01 Top Hat XL added
    [FL Corner.stl, FL Front Panel Lid[acc].stl, FL Inner Panel Lid.stl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]
2023-04-01 File names corrected for Top Hat Standard
    [FL Corner.stl, FL Front Panel Lid[acc].stl, FL Inner Panel Lid.stl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]
2023-04-01 Updating Cad Files
    [ZANDVE_TYPE-Z_0_1.step, ZANDVE_TYPE-Z_0_2.step]
2023-04-01 Update R_Frame_Enclosure Supports Needed.stl
    Issue with stl
    [R_Frame_Enclosure Supports Needed.stl]
2023-04-01 CAD Update
    Replicating fixes from Tower R_Frame issue
    [ZANDVE_TYPE-Z_0_2.step, ZANDVE_TYPE-Z_0_2_1.step]
2023-04-02 Added built in supports
    6 parts impacted
    4x top hat rear corners on STD and XL
    2x on Front Tower frames
    [L_Frame_Enclosure Supports Needed.stl, L_Frame_Enclosure_WSupp.stl, RL Corner Needs Support.stl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]
2023-04-02 Updated Cad
    Added models for supports
    [ZANDVE_TYPE-Z_0_2_1.step, ZANDVE_TYPE-Z_0_2_2.step]
2023-04-02 1
    built in supports, Print in orientation of the .STL, remove the cross extrusion on the printer and relocate the right angle corner brackets to behind the left and right uprights ( see pics for orient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
2023-04-04 Adding Config Examples
    [fluidd.cfg, printer.cfg]
2023-04-04 Folder Name issue
    [fluidd.cfg, printer.cfg]
2023-04-05 Initial load of Type V
    [Beacon_SB_Xcarriage-Left.stl, Beacon_SB_Xcarriage-Right.stl, Cable Chain Bridge_Y Limit.stl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]
2023-04-10 Adding Bottom Skirt Panel clips
    [bottom_panel_clip_x4.stl, bottom_panel_hinge_x2.stl]
2023-04-13 Create STL
2023-04-13 Add files via upload
    Adds a pillow block bearing using already available parts from Ender 5 V-Slot wheels.
    [Mayhem_Final_Left_Stepper.stl]
2023-04-13 Assembled Pictures
2023-04-13 Update README.md
    added Pillow Bearing Mod Description
2023-04-13 Update for clarity
    [Mayhem_Final_Left_Stepper.stl]
2023-04-13 Uploaded Revised Files
    [Left_Stepper_Pillow_Block_Mod.stl, Right_Stepper_1_1_Bearing_Stack.stl]
2023-04-19 Adding option for rear steppers
    Rear steppers are to far away from belt path for some models
    [L Main Top Plate Pocket.stl, R Main Top Plate Pocket.stl]
2023-05-07 Added the upgraded Stepper mounts
    [L Bottom Plate MP.stl, L Bottom Plate.stl, L Frame Top Plate.stl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]
